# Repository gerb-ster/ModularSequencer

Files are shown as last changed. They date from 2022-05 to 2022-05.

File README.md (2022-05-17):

# Modular Sequencer

A modular sequencer consisting of a control module and 1 or more linkable io-modules. Al daisychained together.

## Notes

- All connected by a parallel SPI bus.
- contains 1 serial connected line for discovery
- a termination jumper for the last io-board
- all io-boards start up in a discovery mode
- if io board has termination jumper it sends signal
- control boards send an ID which is registered by io board
- io board goes out of discovery mode and sets discovery line high
- this triggers the same process in the ajasoned io-board module
- this goes on until control board senses a discovery line high
- play mode is then activated
- control board sends a gate active command; board_id + port + on / off
- io board scans inputs, gate on/off, cv value & gate length for all of its 4 ports and sends it to the control board.

## features

### Main Control Board

- tempo pot
- tempo external input (bpm)
- tempo CV input (?)
- start / stop button
- start / stop trigger inputs (?)
- CV output
- CV Portamento
- Gate Output

### IO Board

- 4x CV level pot
- 4x Gate length pot
- 4x Gate on/off toggle switch
- 4x Step indicator LED

## Links

https://www.instructables.com/ATTiny84-I2C-Slave-Arduino-UNO/
https://thecustomizewindows.com/2019/03/how-to-invert-signal-for-arduino-high-to-low-or-the-reverse/
https://docs.arduino.cc/learn/communication/wire

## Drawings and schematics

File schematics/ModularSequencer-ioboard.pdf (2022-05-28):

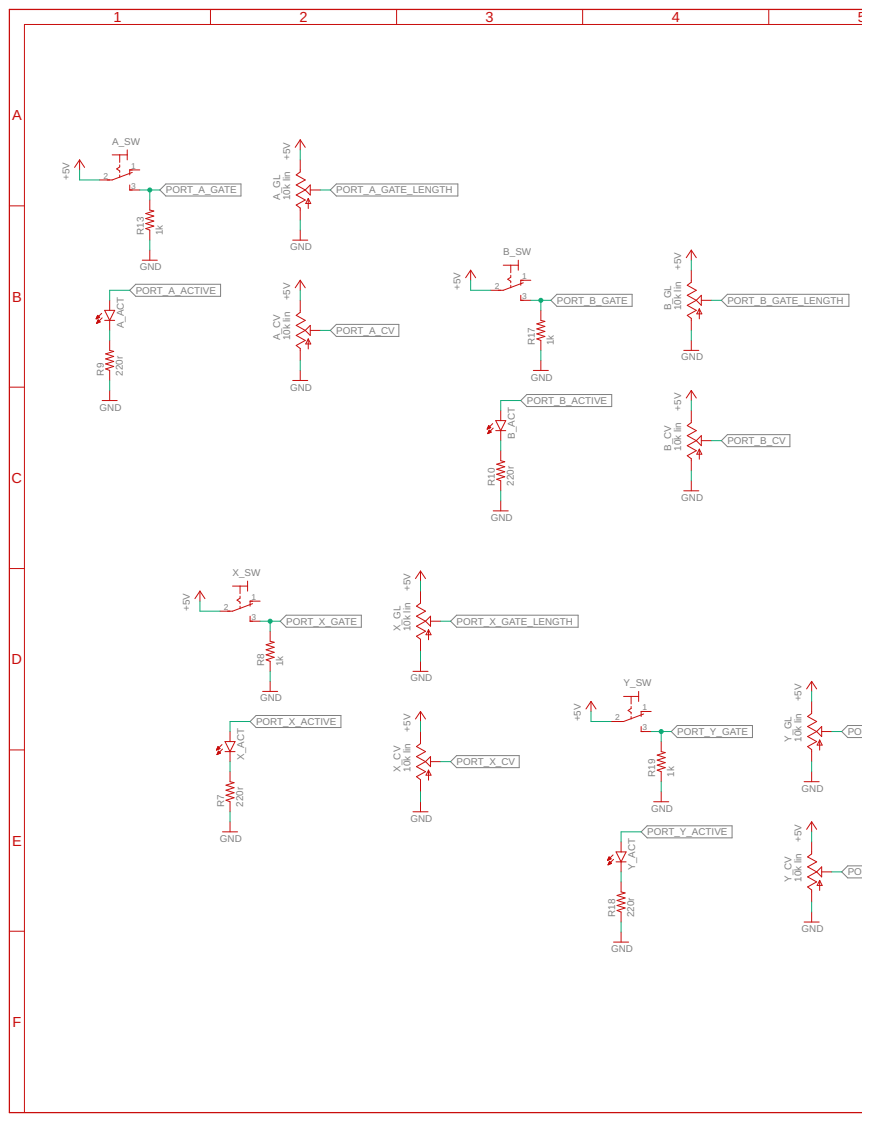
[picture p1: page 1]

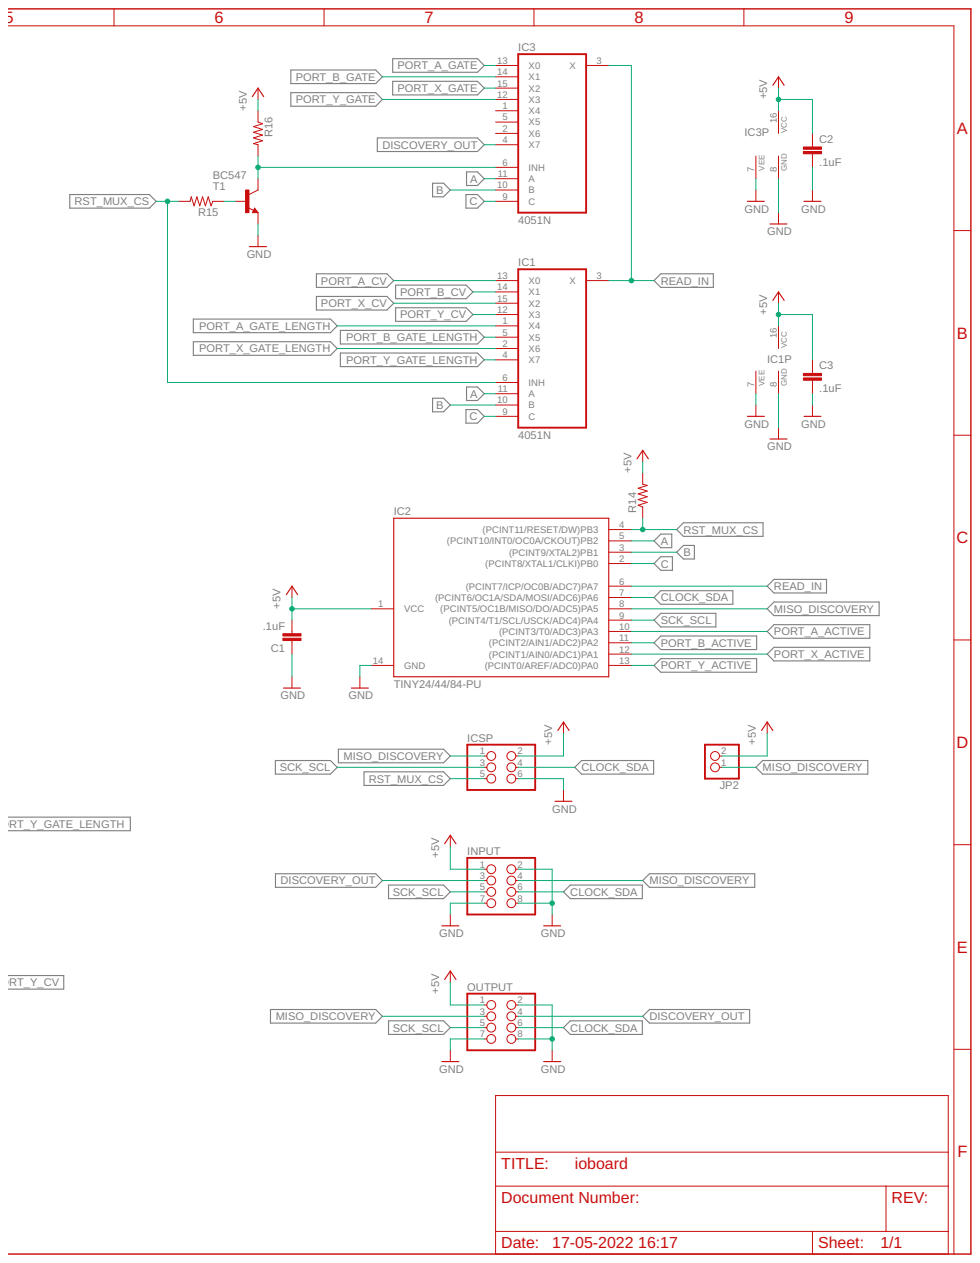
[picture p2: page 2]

Document Number: | REV:

Date: 17-05-2022 16:17 | Sheet: 1/1

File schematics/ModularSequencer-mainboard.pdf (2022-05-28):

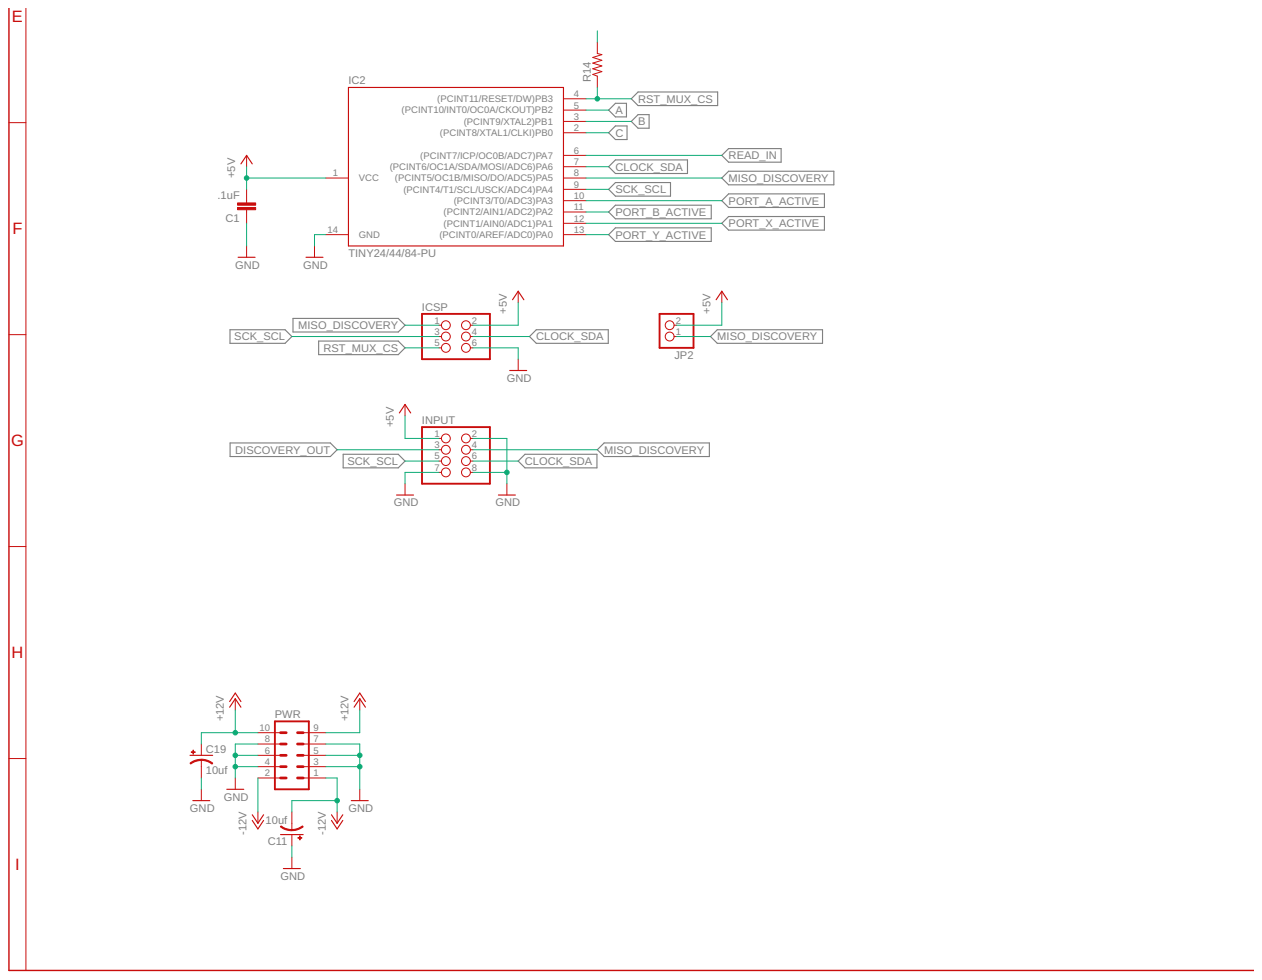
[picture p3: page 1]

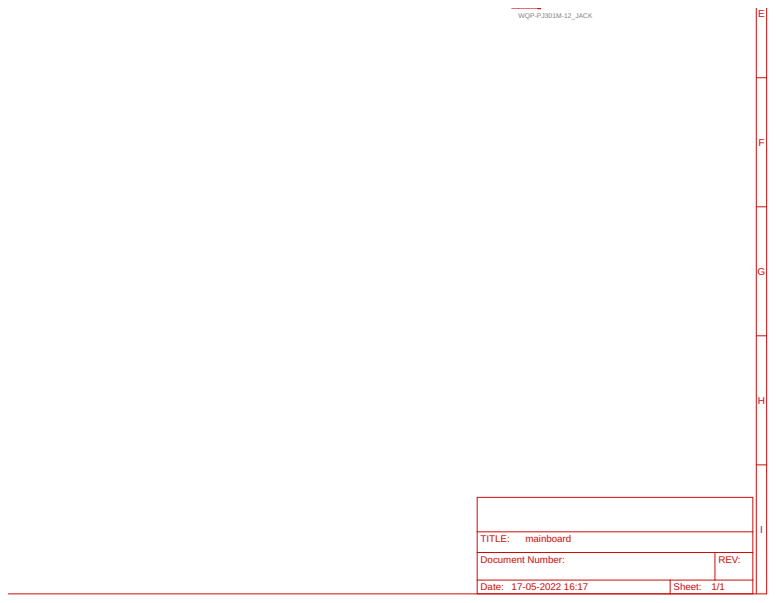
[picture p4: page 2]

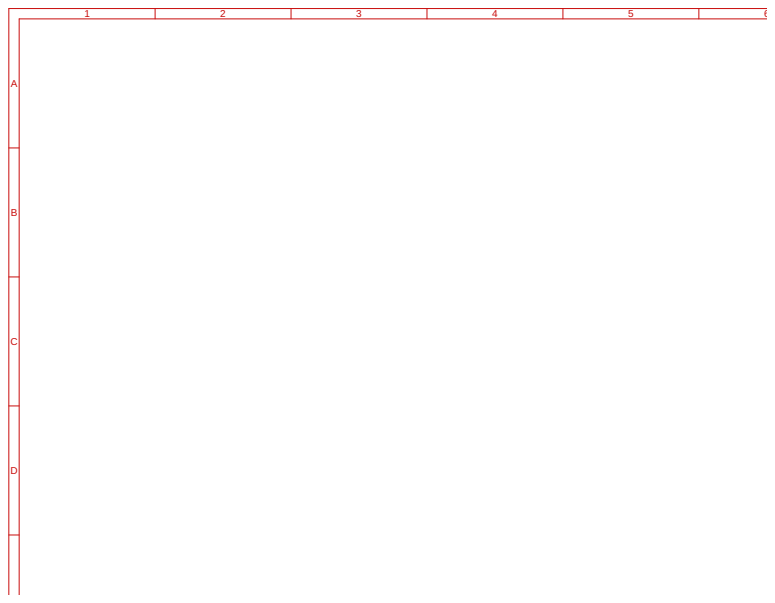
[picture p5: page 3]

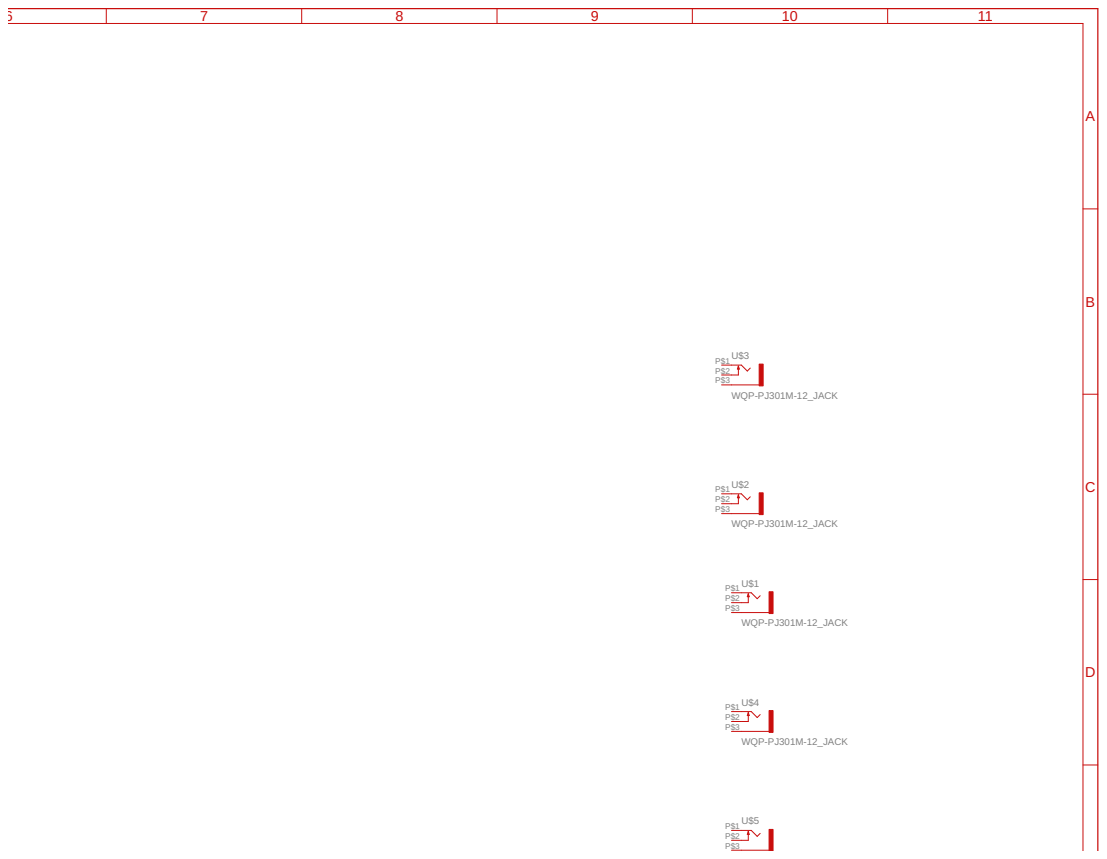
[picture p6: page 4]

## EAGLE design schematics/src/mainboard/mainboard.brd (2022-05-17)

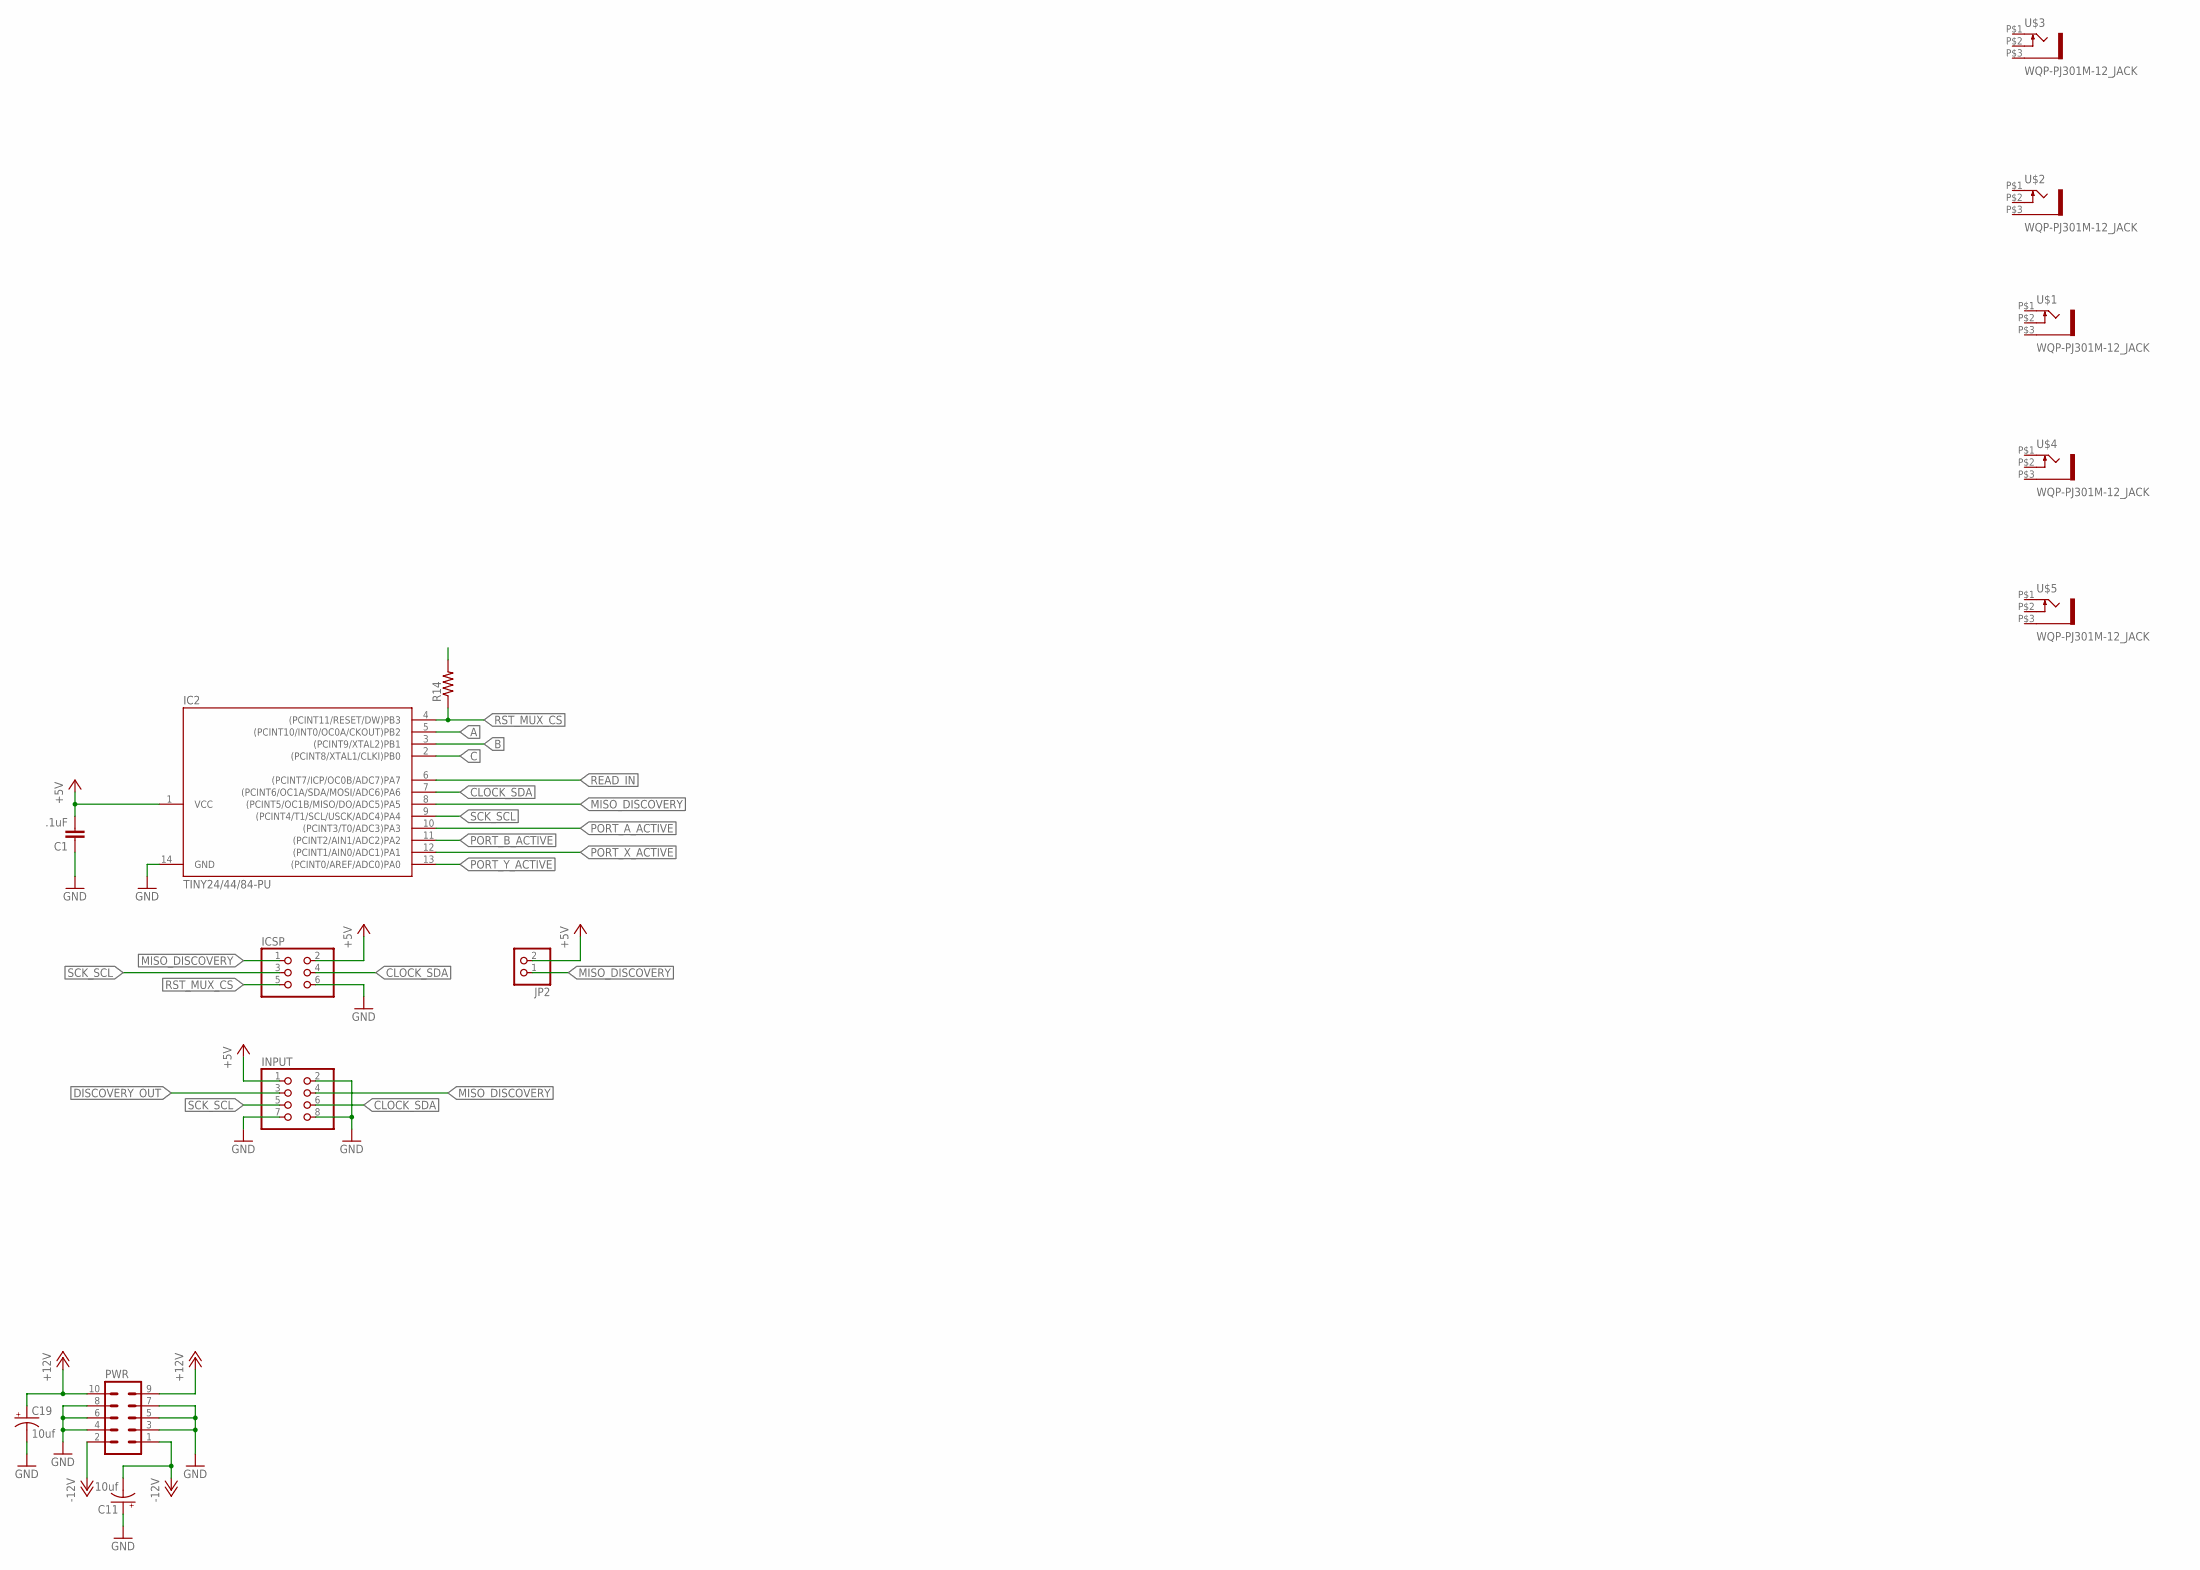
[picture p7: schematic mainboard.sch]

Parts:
C1: .1uF; C050-024X044
C11, C19: 10uf; E2,5-5
IC2: TINY24/44/84-PU; DIL14
ICSP: PINHD-2X3; 2X03
INPUT: PINHD-2X4; 2X04
JP2: PINHD-1X2; 1X02
PWR: ML10
R14: R-US_0204/7; 0204/7
U$1, U$2, U$3, U$4, U$5: WQP-PJ301M-12_JACK

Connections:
+5V: C1.2, IC2.1 (VCC), ICSP.2, INPUT.1, JP2.2, R14.2
+12V: C19.+, PWR.9, PWR.10
-12V: C11.-, PWR.1, PWR.2
A: IC2.5 ((PCINT10/INT0/OC0A/CKOUT)PB2)
B: IC2.3 ((PCINT9/XTAL2)PB1)
C: IC2.2 ((PCINT8/XTAL1/CLKI)PB0)
CLOCK_SDA: IC2.7 ((PCINT6/OC1A/SDA/MOSI/ADC6)PA6), ICSP.4, INPUT.6
DISCOVERY_OUT: INPUT.3
GND: C1.1, C11.+, C19.-, IC2.14 (GND), ICSP.6, INPUT.2, INPUT.7, INPUT.8, PWR.3, PWR.4, PWR.5, PWR.6, PWR.7, PWR.8
MISO_DISCOVERY: IC2.8 ((PCINT5/OC1B/MISO/DO/ADC5)PA5), ICSP.1, INPUT.4, JP2.1
PORT_A_ACTIVE: IC2.10 ((PCINT3/T0/ADC3)PA3)
PORT_B_ACTIVE: IC2.11 ((PCINT2/AIN1/ADC2)PA2)
PORT_X_ACTIVE: IC2.12 ((PCINT1/AIN0/ADC1)PA1)
PORT_Y_ACTIVE: IC2.13 ((PCINT0/AREF/ADC0)PA0)
READ_IN: IC2.6 ((PCINT7/ICP/OC0B/ADC7)PA7)
RST_MUX_CS: IC2.4 ((PCINT11/RESET/DW)PB3), ICSP.5, R14.1
SCK_SCL: IC2.9 ((PCINT4/T1/SCL/USCK/ADC4)PA4), ICSP.3, INPUT.5

Board: 2 copper layers, 14 parts (0 on the bottom side), 8 nets, no tracks yet.

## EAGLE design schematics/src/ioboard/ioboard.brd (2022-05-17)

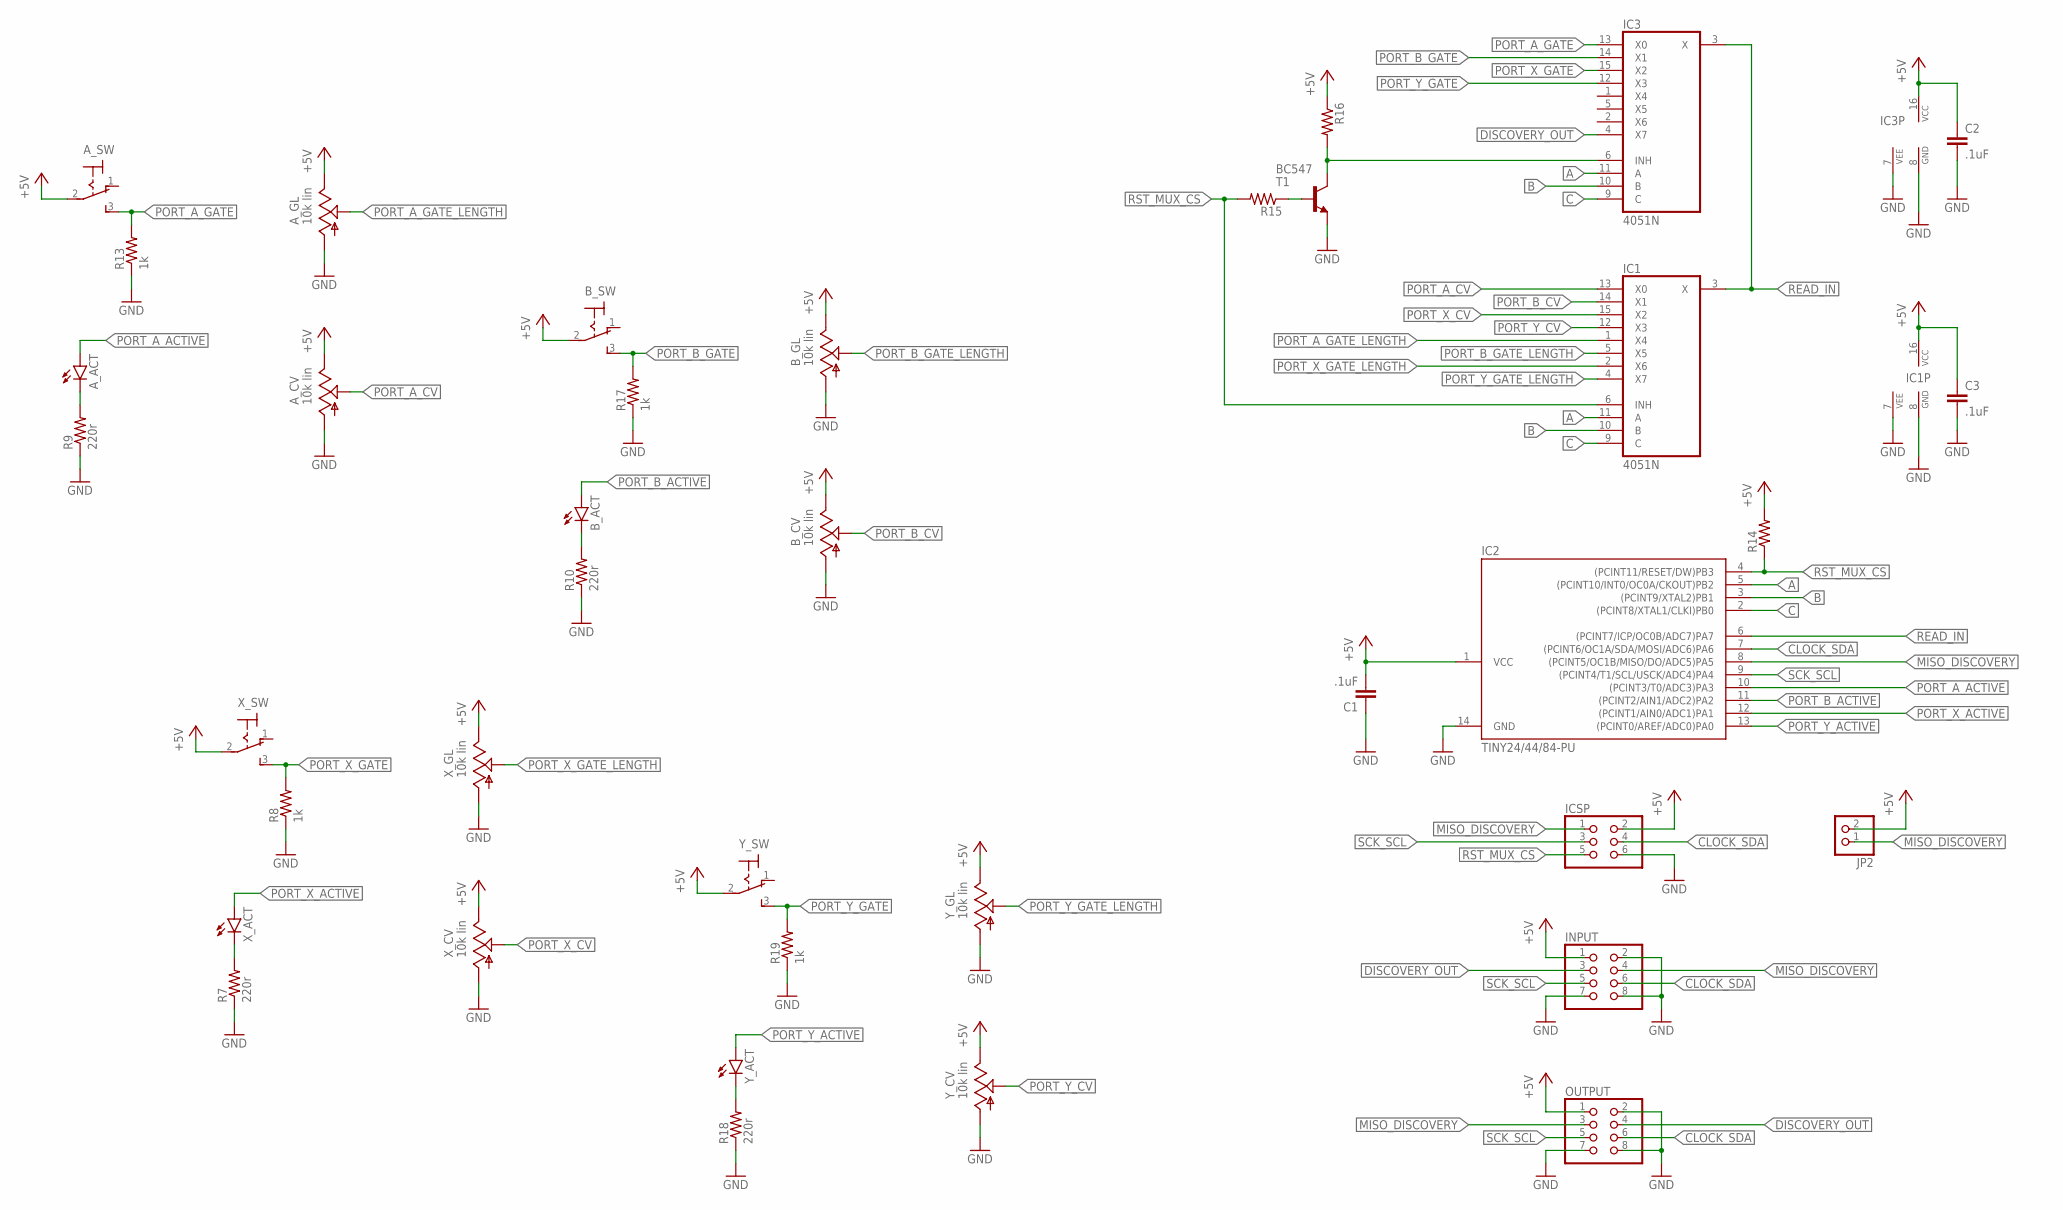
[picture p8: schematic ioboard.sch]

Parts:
A_ACT: LED5MM
A_CV: 10k lin; EVUF
A_GL: 10k lin; EVUF
A_SW: M9040P
B_ACT: LED5MM
B_CV: 10k lin; EVUF
B_GL: 10k lin; EVUF
B_SW: M9040P
C1, C2, C3: .1uF; C050-024X044
IC1, IC3: 4051N; DIL16
IC2: TINY24/44/84-PU; DIL14
ICSP: PINHD-2X3; 2X03
INPUT: PINHD-2X4; 2X04
JP2: PINHD-1X2; 1X02
OUTPUT: PINHD-2X4; 2X04
R7, R9, R10, R18: 220r; 0204/7
R8, R13, R17, R19: 1k; 0204/7
R14, R15, R16: R-US_0204/7; 0204/7
T1: BC547; TO92
X_ACT: LED5MM
X_CV: 10k lin; EVUF
X_GL: 10k lin; EVUF
X_SW: M9040P
Y_ACT: LED5MM
Y_CV: 10k lin; EVUF
Y_GL: 10k lin; EVUF
Y_SW: M9040P

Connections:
+5V: A_CV.3 (E), A_GL.3 (E), A_SW.2, B_CV.3 (E), B_GL.3 (E), B_SW.2, C1.2, C2.1, C3.1, IC1.16 (VCC), IC2.1 (VCC), IC3.16 (VCC), ICSP.2, INPUT.1, JP2.2, OUTPUT.1, R14.2, R16.1, X_CV.3 (E), X_GL.3 (E), X_SW.2, Y_CV.3 (E), Y_GL.3 (E), Y_SW.2
A: IC1.11 (A), IC2.5 ((PCINT10/INT0/OC0A/CKOUT)PB2), IC3.11 (A)
B: IC1.10 (B), IC2.3 ((PCINT9/XTAL2)PB1), IC3.10 (B)
C: IC1.9 (C), IC2.2 ((PCINT8/XTAL1/CLKI)PB0), IC3.9 (C)
CLOCK_SDA: IC2.7 ((PCINT6/OC1A/SDA/MOSI/ADC6)PA6), ICSP.4, INPUT.6, OUTPUT.6
DISCOVERY_OUT: IC3.4 (X7), INPUT.3, OUTPUT.4
GND: A_CV.1 (A), A_GL.1 (A), B_CV.1 (A), B_GL.1 (A), C1.1, C2.2, C3.2, IC1.7 (VEE), IC1.8 (GND), IC2.14 (GND), IC3.7 (VEE), IC3.8 (GND), ICSP.6, INPUT.2, INPUT.7, INPUT.8, OUTPUT.2, OUTPUT.7, OUTPUT.8, R7.1, R8.1, R9.1, R10.1, R13.1, R17.1, R18.1, R19.1, T1.1 (E), X_CV.1 (A), X_GL.1 (A), Y_CV.1 (A), Y_GL.1 (A)
MISO_DISCOVERY: IC2.8 ((PCINT5/OC1B/MISO/DO/ADC5)PA5), ICSP.1, INPUT.4, JP2.1, OUTPUT.3
unnamed: A_ACT.K (C), R9.2
unnamed: B_ACT.K (C), R10.2
unnamed: R15.1, T1.2 (B)
unnamed: R7.2, X_ACT.K (C)
unnamed: R18.2, Y_ACT.K (C)
unnamed: IC3.6 (INH), R16.2, T1.3 (C)
PORT_A_ACTIVE: A_ACT.A, IC2.10 ((PCINT3/T0/ADC3)PA3)
PORT_A_CV: A_CV.2 (S), IC1.13 (X0)
PORT_A_GATE: A_SW.3 (S), IC3.13 (X0), R13.2
PORT_A_GATE_LENGTH: A_GL.2 (S), IC1.1 (X4)
PORT_B_ACTIVE: B_ACT.A, IC2.11 ((PCINT2/AIN1/ADC2)PA2)
PORT_B_CV: B_CV.2 (S), IC1.14 (X1)
PORT_B_GATE: B_SW.3 (S), IC3.14 (X1), R17.2
PORT_B_GATE_LENGTH: B_GL.2 (S), IC1.5 (X5)
PORT_X_ACTIVE: IC2.12 ((PCINT1/AIN0/ADC1)PA1), X_ACT.A
PORT_X_CV: IC1.15 (X2), X_CV.2 (S)
PORT_X_GATE: IC3.15 (X2), R8.2, X_SW.3 (S)
PORT_X_GATE_LENGTH: IC1.2 (X6), X_GL.2 (S)
PORT_Y_ACTIVE: IC2.13 ((PCINT0/AREF/ADC0)PA0), Y_ACT.A
PORT_Y_CV: IC1.12 (X3), Y_CV.2 (S)
PORT_Y_GATE: IC3.12 (X3), R19.2, Y_SW.3 (S)
PORT_Y_GATE_LENGTH: IC1.4 (X7), Y_GL.2 (S)
READ_IN: IC1.3 (X), IC2.6 ((PCINT7/ICP/OC0B/ADC7)PA7), IC3.3 (X)
RST_MUX_CS: IC1.6 (INH), IC2.4 ((PCINT11/RESET/DW)PB3), ICSP.5, R14.1, R15.2
SCK_SCL: IC2.9 ((PCINT4/T1/SCL/USCK/ADC4)PA4), ICSP.3, INPUT.5, OUTPUT.5

Board: 2 copper layers, 38 parts (0 on the bottom side), 33 nets, no tracks yet.

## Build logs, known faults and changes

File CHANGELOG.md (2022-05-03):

# Changelog

All notable changes to this project will be documented in this file.

The format is based on [Keep a Changelog](https://keepachangelog.com/en/1.0.0/),
and this project adheres to [Semantic Versioning](https://semver.org/spec/v2.0.0.html).

## [0.0.1] - 2022-05-03

### Added

- Inintial repo setup
- Added notes

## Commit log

2022-05-04 Fixed schematics & descriptions
2022-05-17 Updated Firmware
    [ModularSequencer-ioboard.GBL, ModularSequencer-ioboard.GBO, ModularSequencer-ioboard.GBP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]
2022-05-18 Updated Faceplates
    [ModularSequencer-ioboard.XLN, ModularSequencer-mainboard.XLN, gerber_job.gbrjob]
2022-05-18 Fixed issues
    [ModularSequencer-ioboard.XLN, ModularSequencer-mainboard.XLN, gerber_job.gbrjob]
2022-05-21 Fixed schematics
    [ModularSequencer-ioboard.XLN, ModularSequencer-mainboard.XLN, gerber_job.gbrjob]
2022-05-28 General updates
    [copper_bottom.gbr, copper_top.gbr, drills.xln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]
